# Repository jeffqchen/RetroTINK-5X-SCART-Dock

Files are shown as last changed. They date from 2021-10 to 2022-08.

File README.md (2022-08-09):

# RetroTINK 5X SCART Dock

Mike Chi's [RetroTINK 5X Pro](https://www.retrotink.com/product-page/5x-pro) is a blessing to the entire retro-gaming community. However the SCART port on the 5X has its issue, not to mention that nobody has any love left for the SCART standard itself. Personally, I'm also a fan of vertical stands for my devices. So here's my approach to tackle the matters.

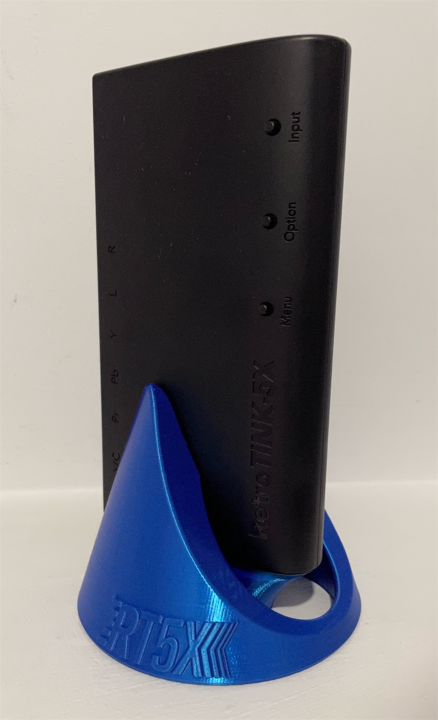
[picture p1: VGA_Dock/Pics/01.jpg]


This dock system puts the RetroTINK 5X into a vertical standing position. It taps into the SCART port, so RGBS + audio signals could be fed into the 5X, while providing extra stability.

------------

There are two version of the dock. One that uses the standard BNC and 3.5mm audio headers, and the other that makes use of my [VGA RGBS + audio pinout standard](https://github.com/jeffqchen/Console-VGA-Dongle-Series).

## [Building The VGA Dock](https://github.com/jeffqchen/RetroTINK-5X-SCART-Dock/tree/main/VGA_Dock)

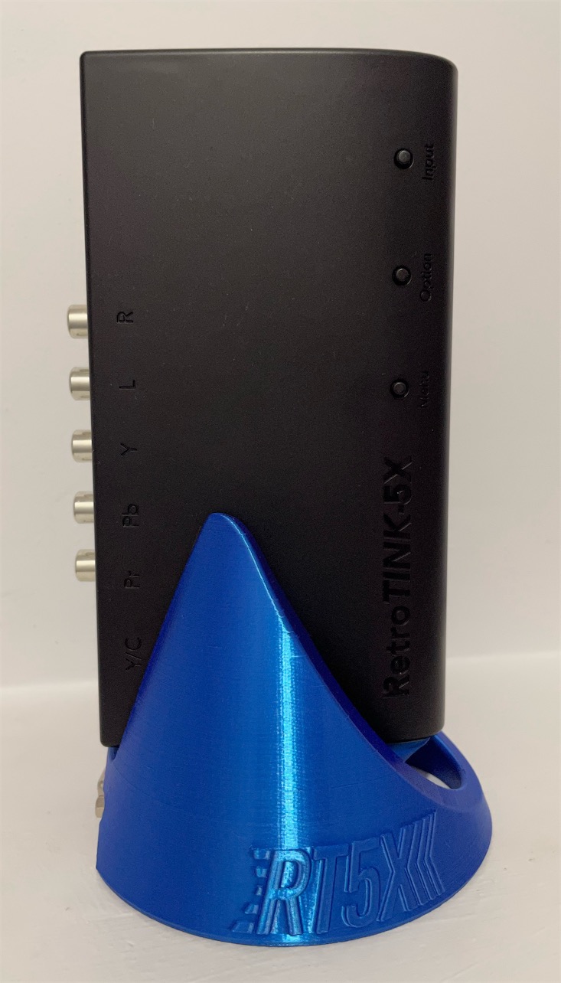
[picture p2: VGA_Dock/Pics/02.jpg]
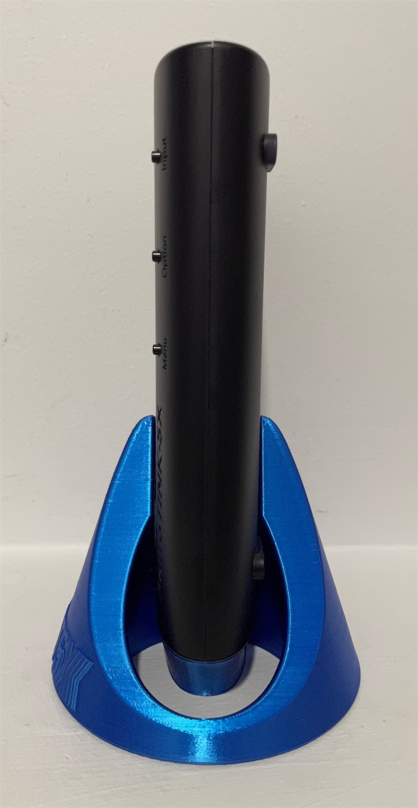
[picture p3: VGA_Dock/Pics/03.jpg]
  

&nbsp;

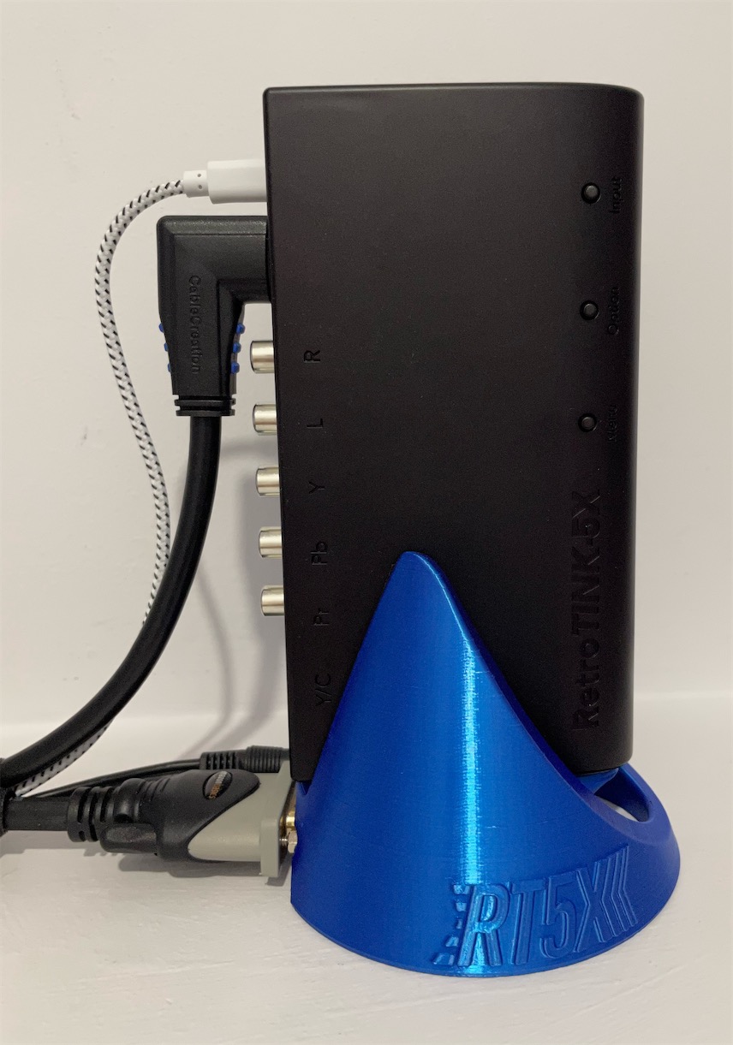
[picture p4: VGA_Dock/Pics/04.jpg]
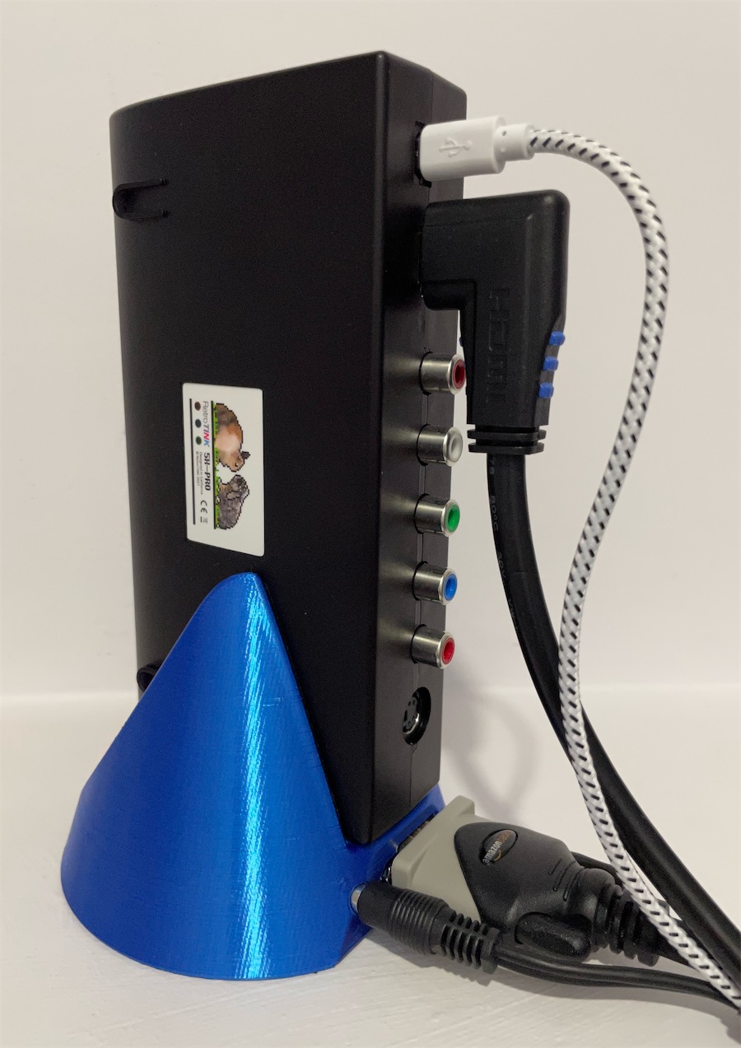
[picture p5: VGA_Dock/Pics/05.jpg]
 

-----------

## [Building The BNC Dock](https://github.com/jeffqchen/RetroTINK-5X-SCART-Dock/tree/main/BNC_Dock)

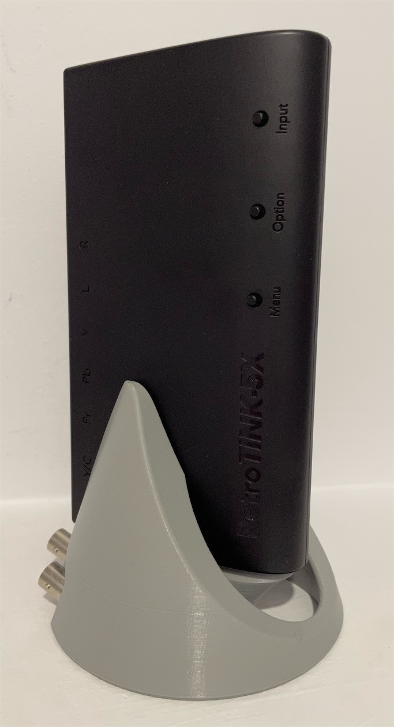
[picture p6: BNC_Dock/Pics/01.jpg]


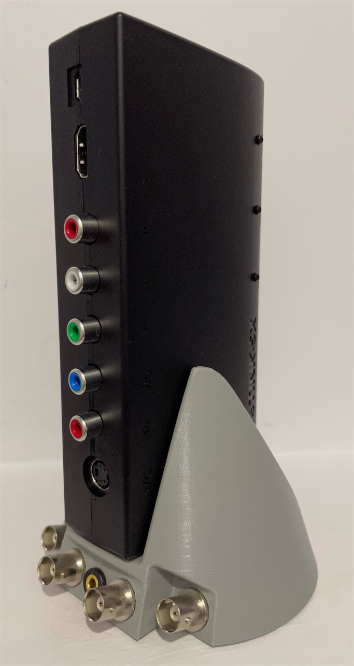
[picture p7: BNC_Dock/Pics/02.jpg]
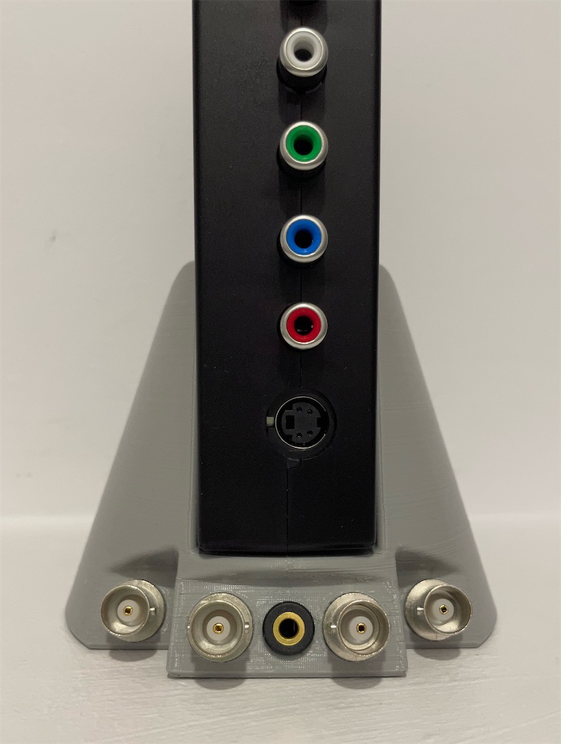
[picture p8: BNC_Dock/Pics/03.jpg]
 

&nbsp;

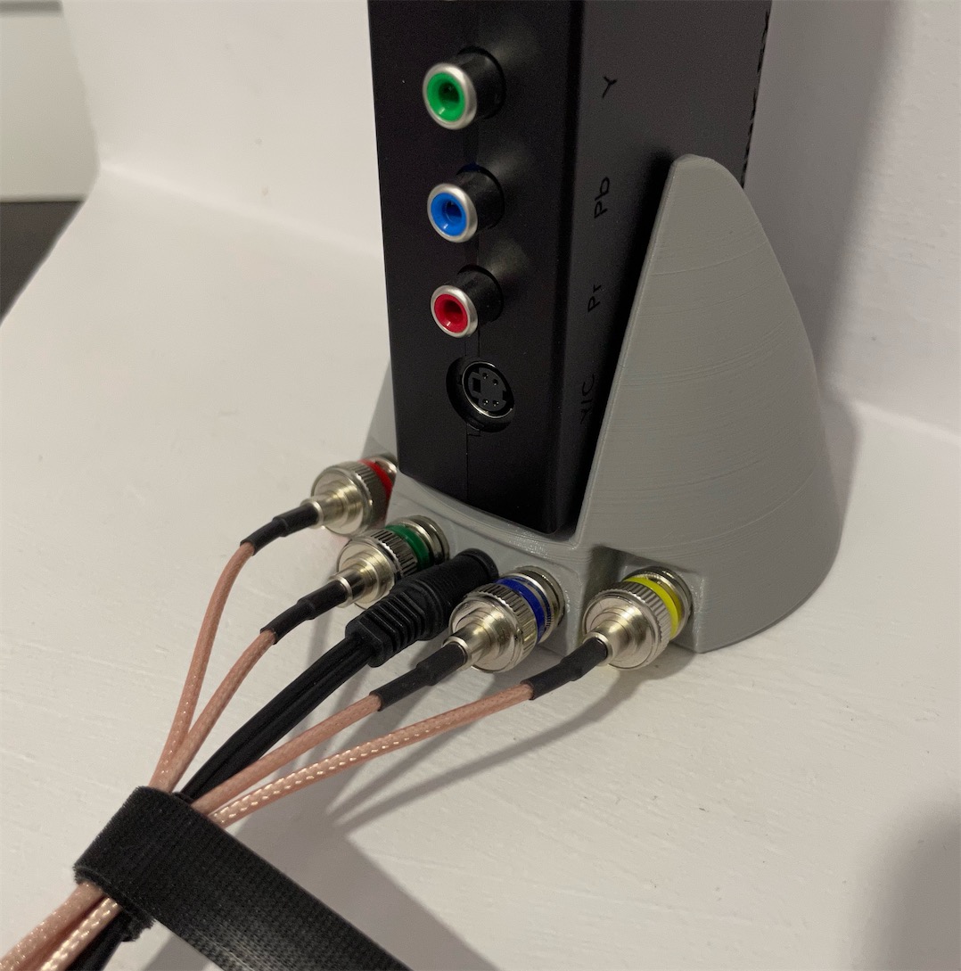
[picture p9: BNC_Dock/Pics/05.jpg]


------------

## Misc

If you are bothered by the single LED inside the RetroTINK 5X, here is a 3D-printed light diffuser that fixes it.

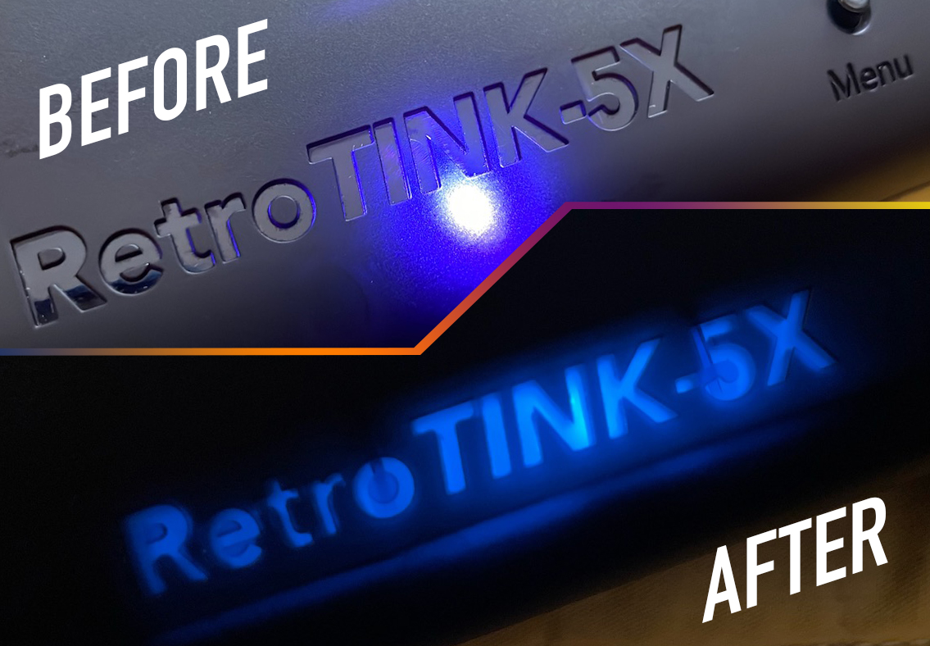
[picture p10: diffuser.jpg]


https://www.thingiverse.com/thing:4981210

------------

## Special Thanks

Mike Chi, creator of the RetroTINK 5X. Helped me in various aspects of this project as well.
- Website: https://www.retrotink.com
- Twitter: https://twitter.com/retrotink2

------------

Shield: [][cc-by-sa]

This work is licensed under a
[Creative Commons Attribution-ShareAlike 4.0 International License][cc-by-sa].

[][cc-by-sa]

[cc-by-sa]: http://creativecommons.org/licenses/by-sa/4.0/
[cc-by-sa-image]: https://licensebuttons.net/l/by-sa/4.0/88x31.png
[cc-by-sa-shield]: https://img.shields.io/badge/License-CC%20BY--SA%204.0-lightgrey.svg

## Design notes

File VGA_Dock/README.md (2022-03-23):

# Building The RetroTINK 5X Pro VGA Dock

  

&nbsp;

 

-------

## Parts

- [PCB](https://oshpark.com/shared_projects/VoWFgH5Z)

- VGA Port Slim, Female - [Link](https://github.com/jeffqchen/JeffParts/blob/main/Connectors/HD15/Slim/Female%20PCB/info.md)

- Vertical 3.5mm Headphone Jack - [Link](https://github.com/jeffqchen/JeffParts/blob/main/Connectors/3.5mm%20Audio%20Jack/Vertical%205-Pin%20PCB/info.md)

- SCART Male Plug, Cable Type - [Link](https://github.com/jeffqchen/JeffParts/blob/main/Connectors/SCART/Male%20Cable/info.md)

- [1x] M3x16mm Hex Screws and Nuts - [Link](https://github.com/jeffqchen/JeffParts/blob/main/Parts/M2%20M3%20Hex%20Screw%20%26%20Nut/info.md)

- SMD Resistor 0603 470 Ohm, [2x] SMD Capacitor 0603 10uF, 6.3V
  - Buy from wherever you feel like (DigiKey, Mouser, Amazon, Aliexpress, eBay)

---------

## 3D Printing

Print the models in their original orientations. Support is necessary for the main body. 0.16mm or lower layer height is suggested for better aesthetic.

If you are afraid of the sides of the 5X being scratched agains the dock, apply some electric tape on the inside helps.

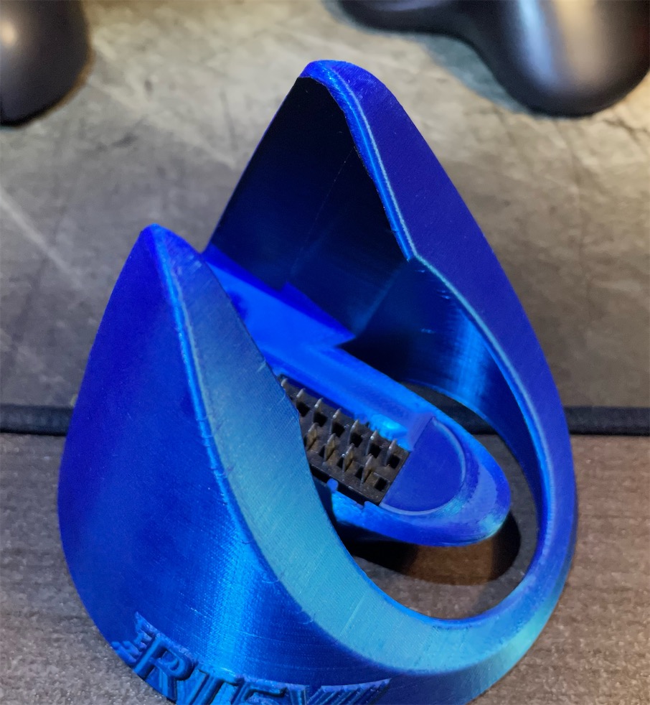
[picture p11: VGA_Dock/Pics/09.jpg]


---------

## Soldering SMD Components

Solder in the SMD components first.

Populate the 470 Ohm resistor regardless of the use case. I have tested that even if the signal was attenuated before, this double attenuation didn't mess things up. In the rare case when it does, short the jumper pads with solder to bypass the on-board attenuation.

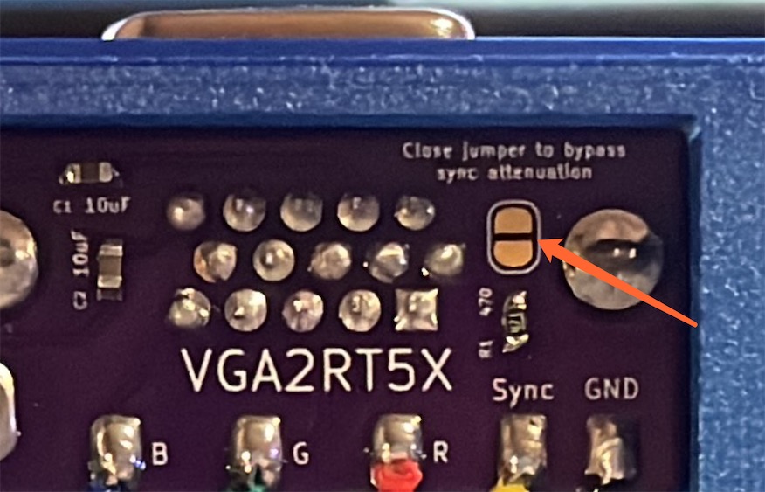
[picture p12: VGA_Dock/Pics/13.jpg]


---------

## Preparing The SCART Plug

For the SCART plug, I suggest soldering color-coded wires before putting it into the main body. Leave some length so you won't be constrained afterwards.

The pinout is as followed:

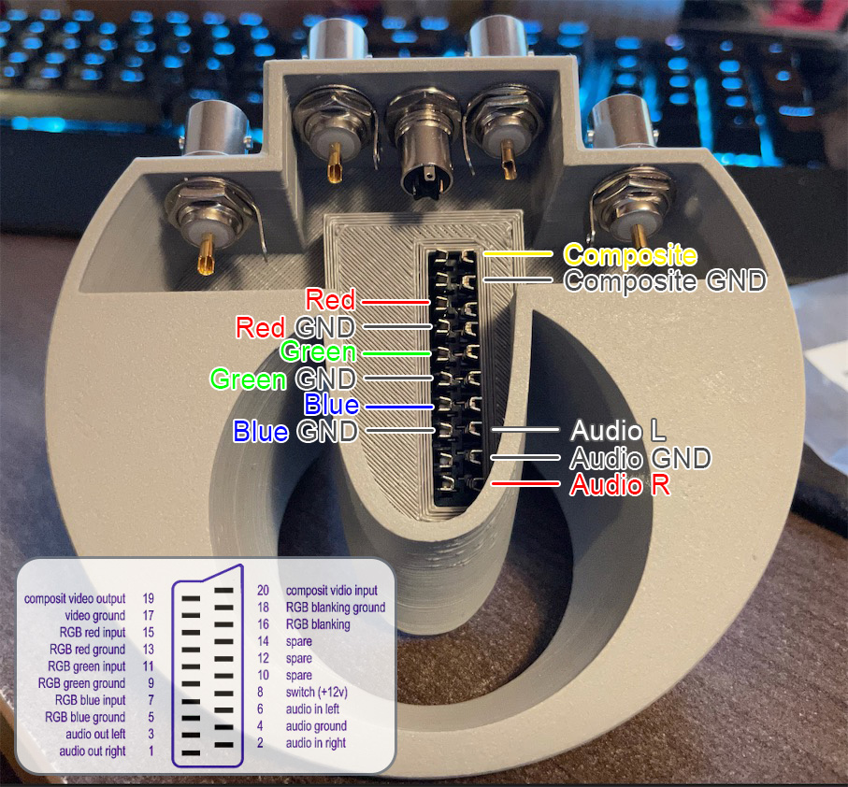
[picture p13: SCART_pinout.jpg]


Note: You can use any of the ground pins for ground. It makes minimal difference and there's no need to hook up all the grounds together, since they all merge right inside the 5X anyway.

---------

## Assembly

Turn the main body piece upside down. Drop the VGA port and 3.5mm jack into the cavity, then secure them with the port spacer piece.

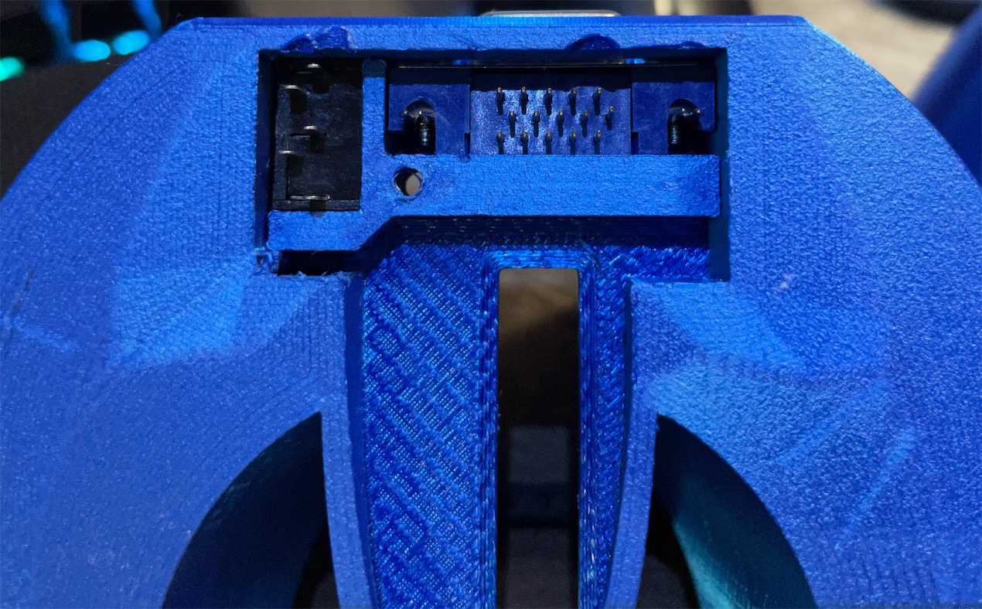
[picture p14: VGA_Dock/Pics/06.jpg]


Then, lay over the PCB on top of the ports, and secure the assembly with the M3x16mm screw and nut. Make sure you don't over tighten it or it will damage the plastic and/or the PCB.

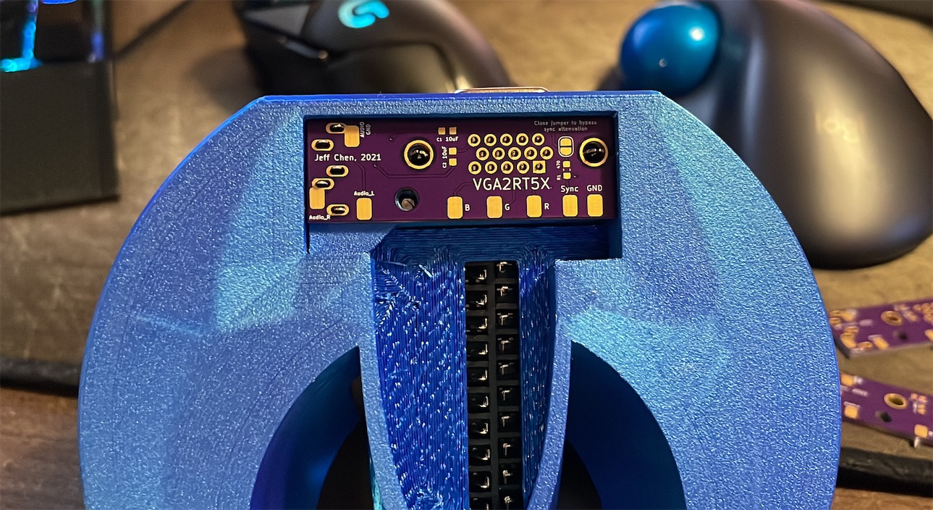
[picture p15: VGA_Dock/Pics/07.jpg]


Now, feed the SCART plug through the opening on the main body with wires attached.

Note the cutout on the sides of the SCART plug, and align them with the notches on the main body of the dock. Push the plug down into the main body.

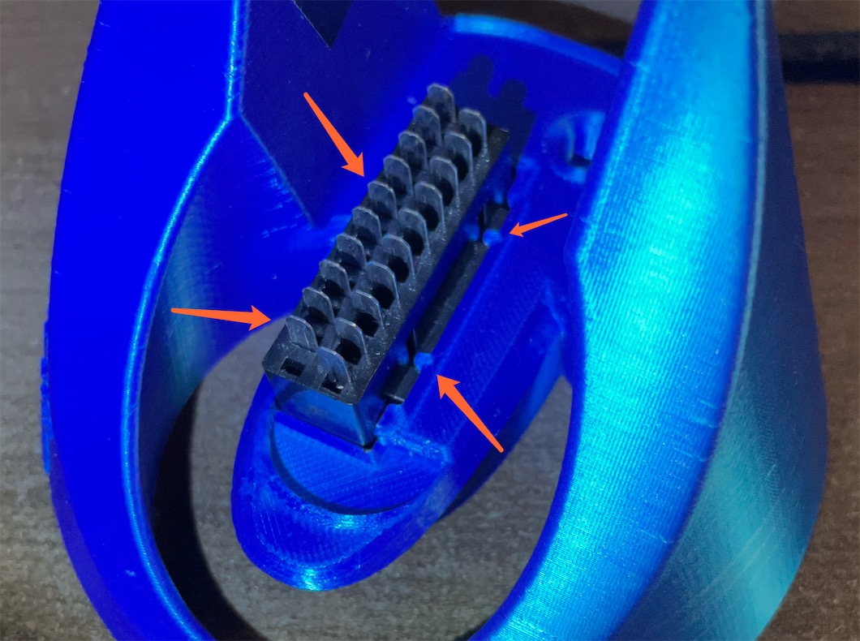
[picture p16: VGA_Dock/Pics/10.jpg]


Then, slide the SCART plug inwards, and then press in the printed  SCART stopper piece to secure the assembly.

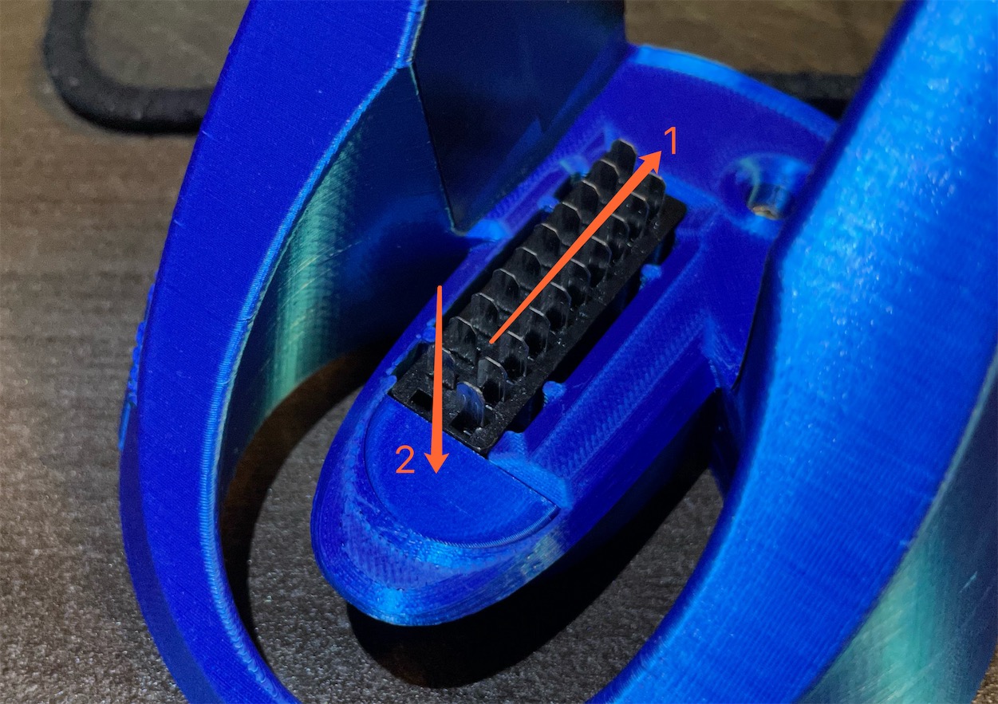
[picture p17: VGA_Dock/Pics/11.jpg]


In case if you needed to remove the SCART plug, use the hole on the bottom side to poke out the SCART stoppper piece.

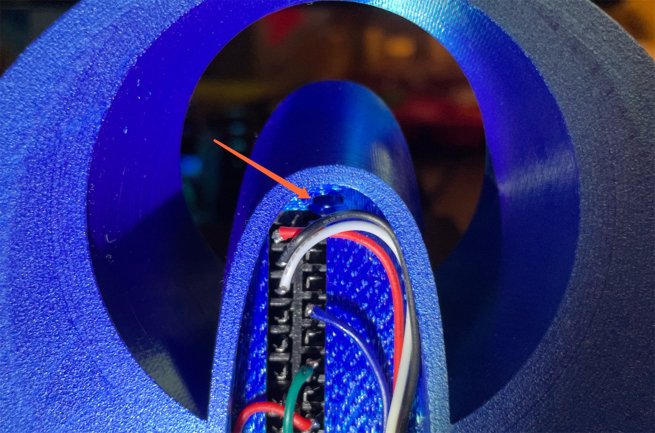
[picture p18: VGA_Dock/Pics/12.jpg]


At last, solder the wires to their respective pads on the PCB.

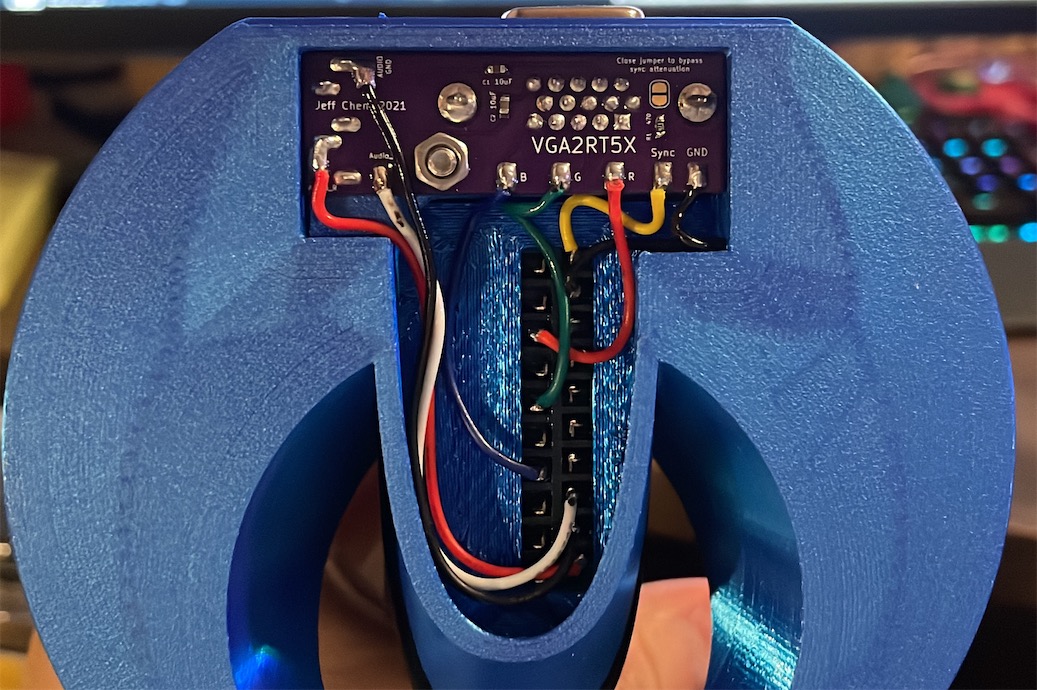
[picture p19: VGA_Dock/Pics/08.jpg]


You might want to protect the PCB with a piece of electric tape. But everything should be off the table regardless.

--------

## Docking

When docking the 5X, make sure to line it up correctly. If it wouldn't go in, it's probably not lined up right.

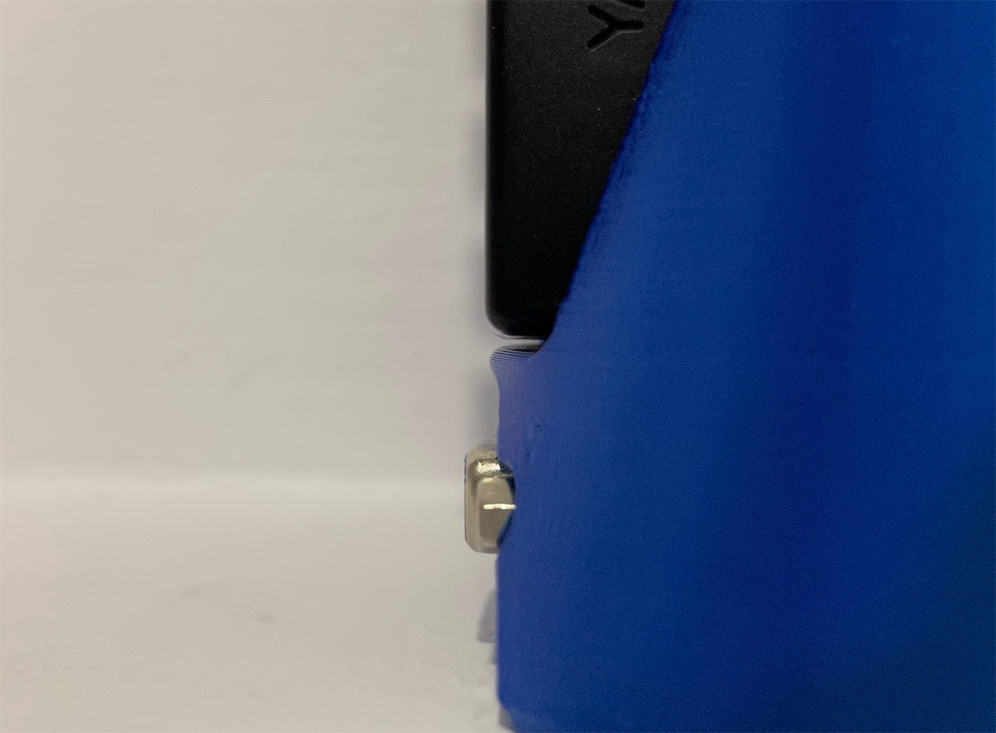
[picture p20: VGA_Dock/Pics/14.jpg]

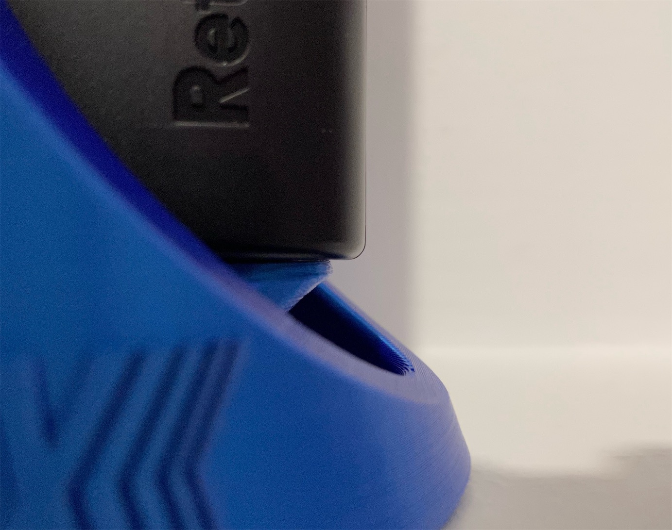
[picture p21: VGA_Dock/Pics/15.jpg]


--------

## "Universal" Attenuation Hack

If your RT5X is frequently moved between TTL sync and attenuated sync device chains, you may use a 150 Ohm resistor for the on-board attenuation as a "universal" hack.

The RT5X will be receiving a 1.5V Vp-p sync when connected to TTL-level sync (which is ok according to Mike), and around 0.28V to 0.4V Vp-p when connected to attenuated sync. None of these are optimal, but both seem to work. If it introduces too much issues, you can always revert to the original and standard 470 Ohm value.

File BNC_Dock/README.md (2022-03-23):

# Building The RetroTINK 5X Pro VGA Dock



 

&nbsp;



-------

## Parts

- [4x] BNC Headers, 75 Ohm, panel mount, solder cup (50 Ohm also works but not preferable) - [Link](https://github.com/jeffqchen/JeffParts/blob/main/Connectors/BNC%20Header/Panel%20Mount/Female/info.md)

- 3.5mm Audio Jack, panel mount - [Link](https://github.com/jeffqchen/JeffParts/blob/main/Connectors/3.5mm%20Audio%20Jack/Panel%20Mount/info.md)

- SCART Male Plug, Cable Type - [Link](https://github.com/jeffqchen/JeffParts/blob/main/Connectors/SCART/Male%20Cable/info.md)

- Resistor 470 Ohm 1/4W
  - Buy from wherever you feel like (DigiKey, Mouser, Amazon, Aliexpress, eBay)
---------

## 3D Printing

Print the models in their original orientations. Support is necessary for the main body. 0.16mm or lower layer height is suggested for better aesthetic.

The bottom piece is for protecting the innards of the dock. It's optional.

If you are afraid of the sides of the 5X being scratched agains the dock, apply some electric tape on the inside helps.



---------

## Preparing The SCART Plug

For the SCART plug, I suggest soldering color-coded wires before putting it into the main body. Leave some length so you won't be constrained afterwards.

The pinout is as followed:



---------

## Assembly

Feed the SCART plug through the opening on the main body with wires attached.

Note the cutout on the sides of the SCART plug, and align them with the notches on the main body of the dock. Push the plug down into the main body.



Then, slide the SCART plug inwards, and then press in the printed  SCART stopper piece to secure the assembly.



Fit all the BNC headers and the 3.5mm jack into the back of the main body.

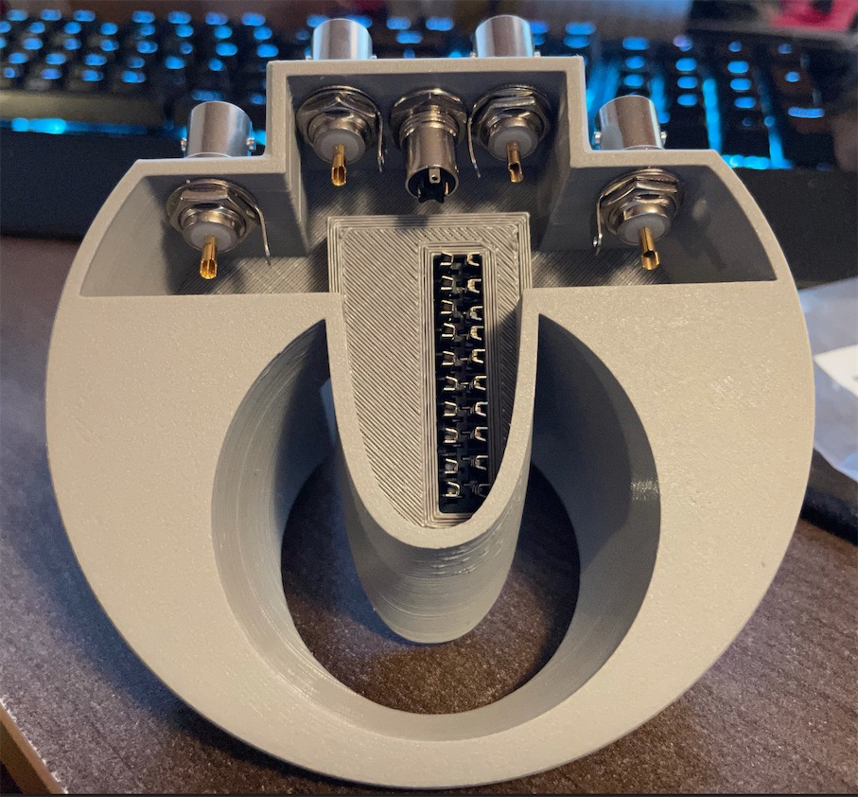
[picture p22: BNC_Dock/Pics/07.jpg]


At last, solder the wires to their respective BNC/audio jack.

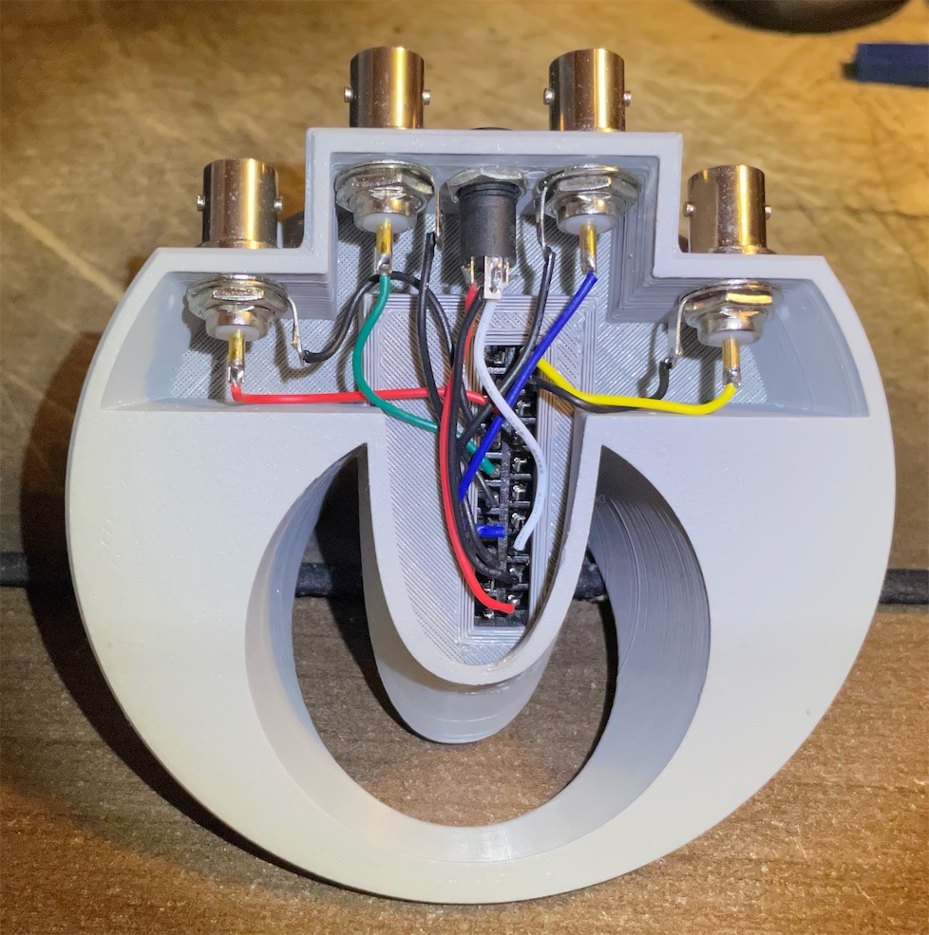
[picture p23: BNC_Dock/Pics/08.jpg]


Using a 470 Ohm resistor on the sync line is highly recommended. Add a piece of heat-shrink tube over the resistor for insulation.

I suggest going in the R > G > B > S order so you don't have to remember.

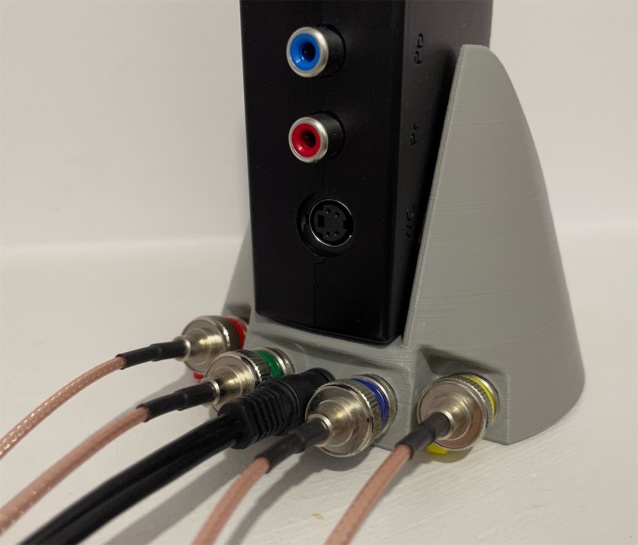
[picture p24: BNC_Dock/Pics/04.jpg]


To protect the bottom of the dock, you could consider printing the bottom piece for the dock.

--------

## Docking

When docking the 5X, make sure to line it up correctly. If it wouldn't go in, it's probably not lined up right.




--------

## "Universal" Attenuation Hack

If your RT5X is frequently moved between TTL sync and attenuated sync device chains, you may use a 150 Ohm resistor for the on-board attenuation as a "universal" hack.

The RT5X will be receiving a 1.5V Vp-p sync when connected to TTL-level sync (which is ok according to Mike), and around 0.28V to 0.4V Vp-p when connected to attenuated sync. None of these are optimal, but both seem to work. If it introduces too much issues, you can always revert to the original and standard 470 Ohm value.

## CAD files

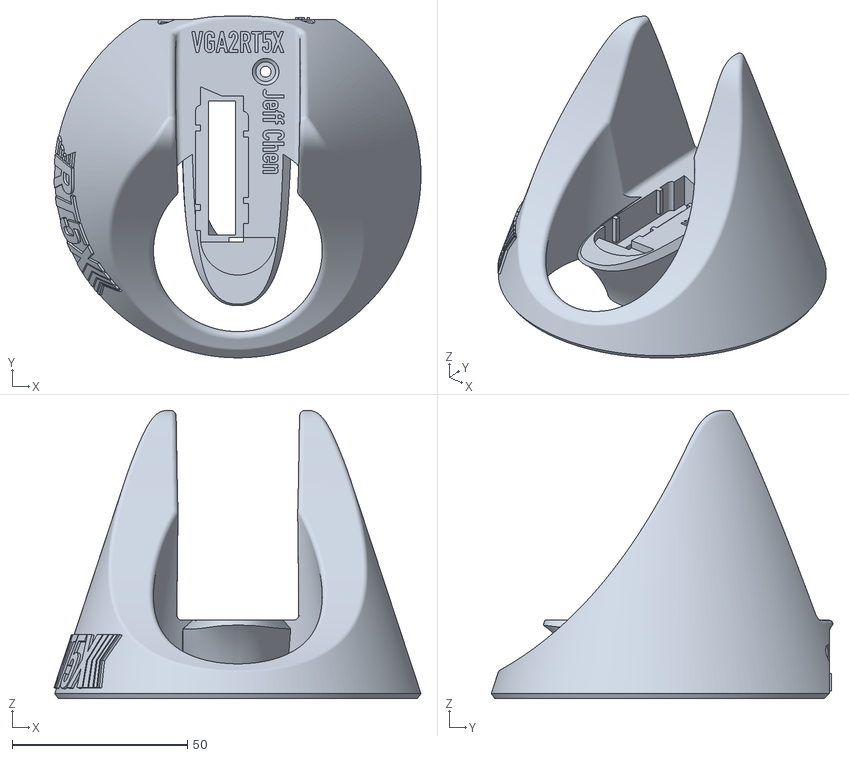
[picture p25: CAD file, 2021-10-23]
VGA_Dock/3D Print/Main Body.stl
104.6 x 97.3 x 82.1

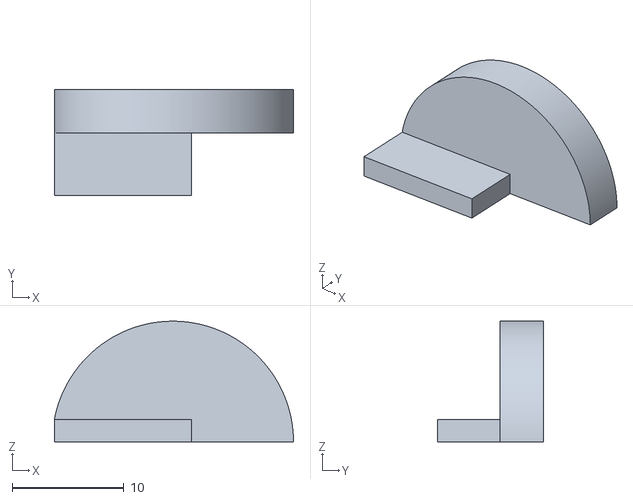
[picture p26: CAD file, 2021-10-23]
BNC_Dock/3D Print/SCART Stopper.stl
21.4 x 9.49 x 10.8

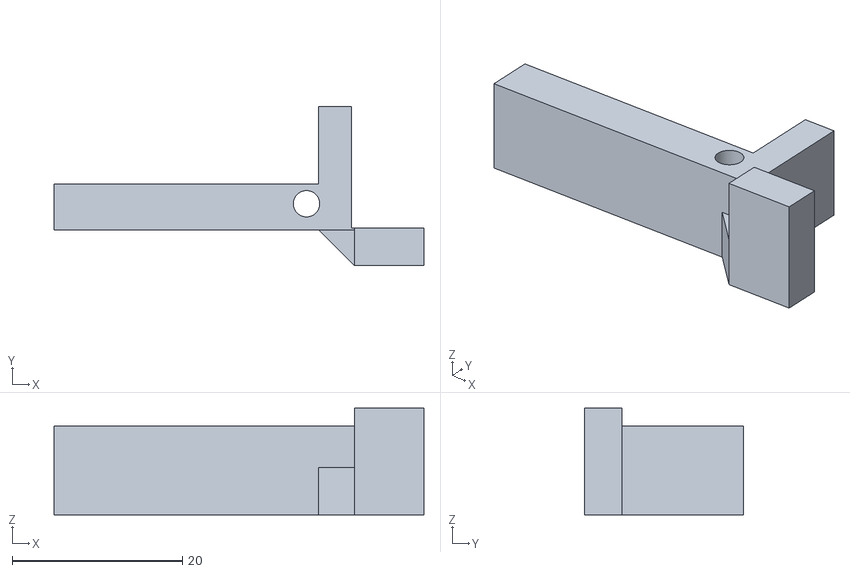
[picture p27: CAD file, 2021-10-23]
VGA_Dock/3D Print/Port Spacer.stl
43.5 x 18.7 x 12.6

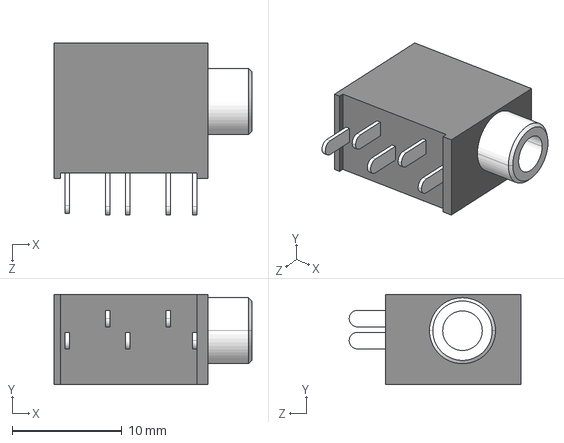
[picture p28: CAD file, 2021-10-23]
VGA_Dock/KiCAD/VGA2RT5X/Files/3.5MM_vertical/CUI_DEVICES_SJ1-3535N.step
18.0 x 8.20 x 15.6 mm

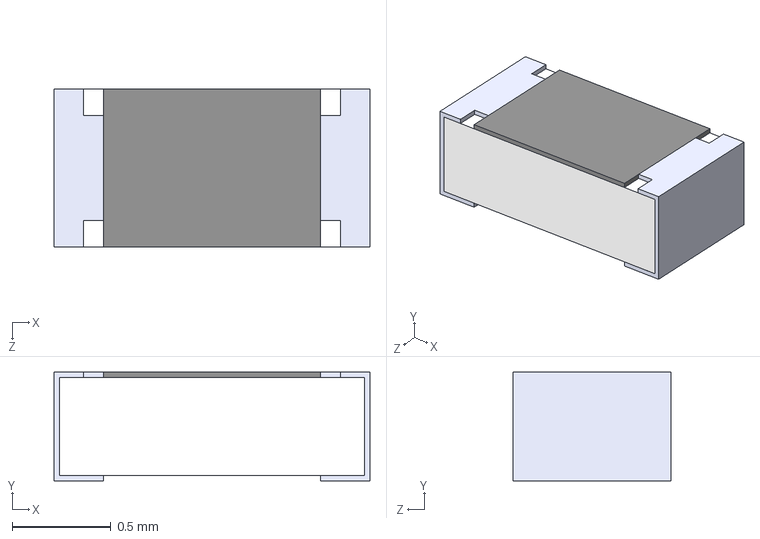
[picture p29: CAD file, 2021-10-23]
VGA_Dock/KiCAD/VGA2RT5X/Files/Resistor_0603/RE0603FRE071KL.step
1.60 x 0.55 x 0.8 mm

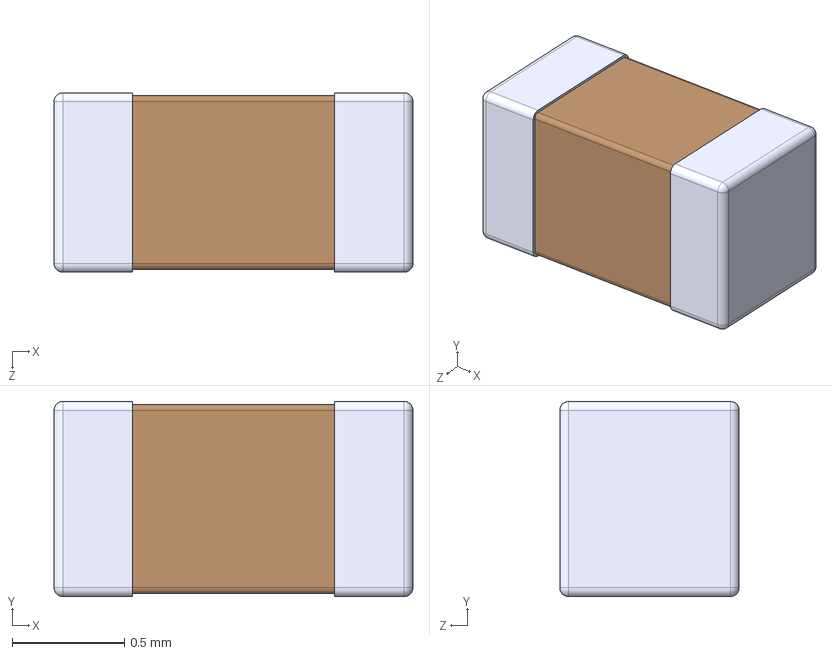
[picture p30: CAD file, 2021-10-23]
VGA_Dock/KiCAD/VGA2RT5X/Files/SMD_Cap/C0603C180K4HAC7867.step
1.60 x 0.87 x 0.8 mm

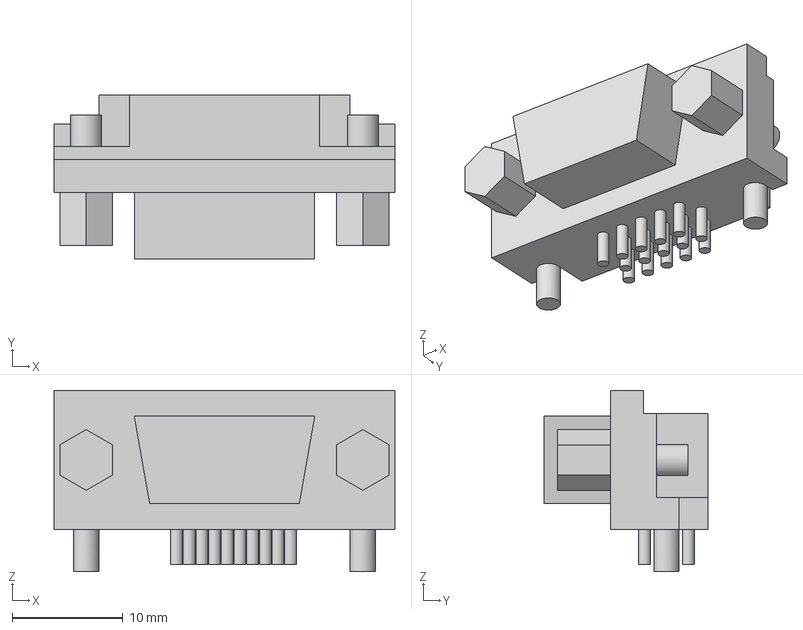
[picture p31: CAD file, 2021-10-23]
VGA_Dock/KiCAD/VGA2RT5X/Files/VGA/VGA Female Slim.step
30.8 x 14.8 x 16.4 mm

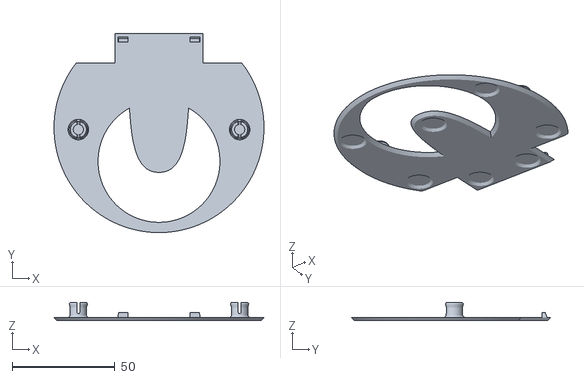
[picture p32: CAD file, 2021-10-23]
BNC_Dock/3D Print/Bottom.stl
102.3 x 97.0 x 9.00

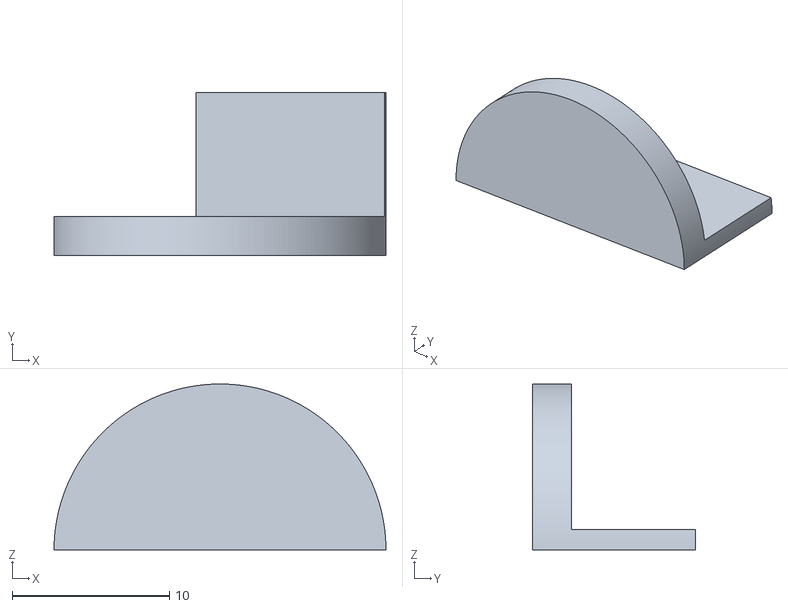
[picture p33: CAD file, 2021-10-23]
VGA_Dock/3D Print/SCART Stopper.stl
21.1 x 10.4 x 10.6

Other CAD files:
BNC_Dock/3D Print/Bottom - No Dimple.stl

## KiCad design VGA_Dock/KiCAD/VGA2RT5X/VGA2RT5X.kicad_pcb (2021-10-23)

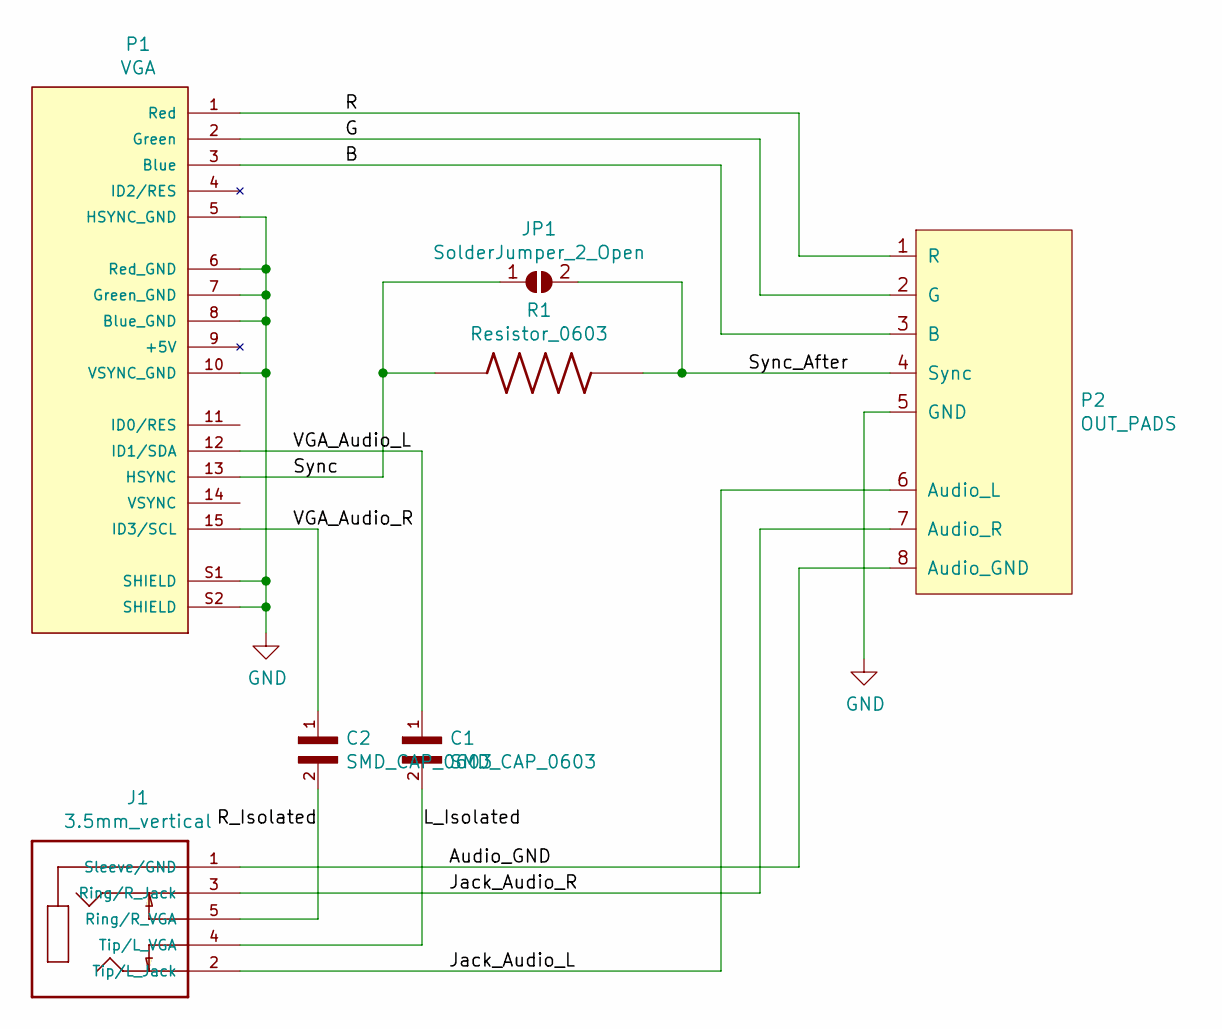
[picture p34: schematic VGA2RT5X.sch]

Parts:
C1, C2: SMD_CAP_0603; SMD_Cap_0603
J1: 3.5mm_vertical; 3.5mm_Jack_5p; PARTREV 1.01
JP1: SolderJumper_2_Open; SolderJumper-2_P1.3mm_Open_RoundedPad1.0x1.5mm
P1: VGA; VGA_female_rightangle_slim; PARTREV N/A
P2: OUT_PADS; Output_Pads
R1: Resistor_0603

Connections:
/Audio_GND: J1.1 (Sleeve/GND), P2.8 (Audio_GND)
/B: P1.3 (Blue), P2.3 (B)
/G: P1.2 (Green), P2.2 (G)
/Jack_Audio_L: J1.2 (Tip/L_Jack), P2.6 (Audio_L)
/Jack_Audio_R: J1.3 (Ring/R_Jack), P2.7 (Audio_R)
/L_Isolated: C1.2, J1.4 (Tip/L_VGA)
/R: P1.1 (Red), P2.1 (R)
/R_Isolated: C2.2, J1.5 (Ring/R_VGA)
/Sync: JP1.1 (A), P1.13 (HSYNC), R1.1
/Sync_After: JP1.2 (B), P2.4 (Sync), R1.2
/VGA_Audio_L: C1.1, P1.12 (ID1/SDA)
/VGA_Audio_R: C2.1, P1.15 (ID3/SCL)
GND: P1.5 (HSYNC_GND), P1.6 (Red_GND), P1.7 (Green_GND), P1.8 (Blue_GND), P1.10 (VSYNC_GND), P1.S1 (SHIELD), P1.S2 (SHIELD), P2.5 (GND)

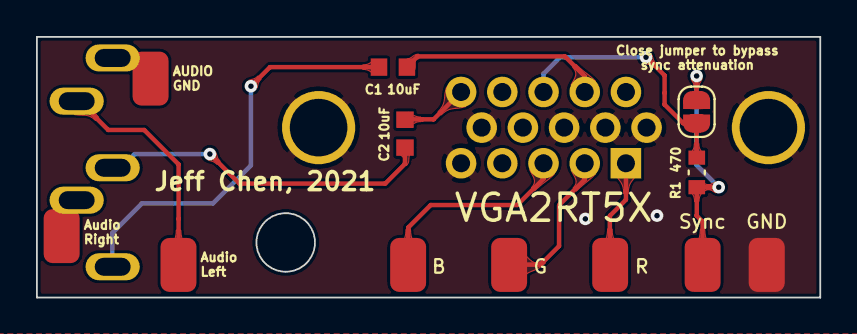
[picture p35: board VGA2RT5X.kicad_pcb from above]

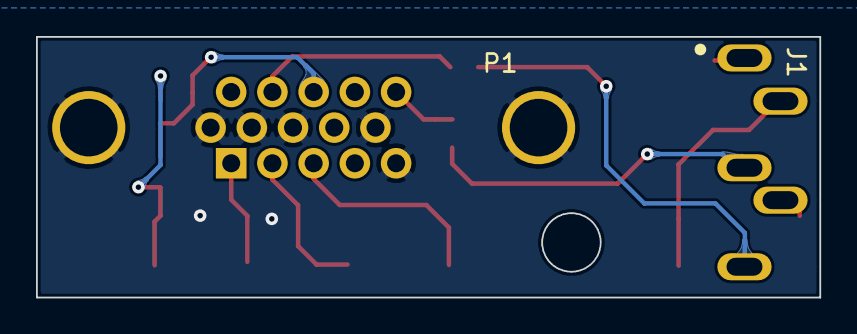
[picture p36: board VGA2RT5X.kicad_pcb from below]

Board: 2 copper layers, 43.5 x 14.5 mm, 7 parts (2 on the bottom side), 13 nets.

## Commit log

2021-10-23 Initial Update
    [Bottom - No Dimple.stl, Bottom.stl, C0603C180K4HAC7867.step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]
2021-10-23 Pics and readme
    [Bottom - No Dimple.stl, Bottom.stl, C0603C180K4HAC7867.step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]
2021-10-23 Updated 3D model for VGA dock
    [Main Body.stl, Port Spacer.stl, Stopper.stl]
2021-10-23 Update VGA dock readme
    [SCART Stopper.stl]

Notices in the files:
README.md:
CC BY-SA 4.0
